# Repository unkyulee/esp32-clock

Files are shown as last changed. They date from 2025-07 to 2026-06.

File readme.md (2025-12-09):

# The Clock 

"The Clock" is a DIY project for people who care about how things look as much as how they work. Clean, minimal, and a little bit obsessive, it is designed to evolve over time. New design ideas, new cases, new features. The long term goal is to build the ultimate desk clock.

---

## What is this project about?

The Clock is:

* A beautiful desk clock that feels at home next to a notebook, a mechanical keyboard, or your favorite pen.
* DIY friendly, using simple materials and straightforward steps.
* Design first, with focus on proportions, light, texture, and shape.
* Iterative, improving in small steps toward a more refined result each time.

---

## What can it do?

Right now, The Clock focuses on doing the basics really well:

* Show the time
* Sync automatically over WiFi
* Optional alarm with a small buzzer

## BOM

- 4x M3 Hex Screw Length 20mm
- 4x M3 Heated Inserts OD 4.5mm Length 3mm
- 1x [EC11 15mm Half handle](https://it.aliexpress.com/item/1005005983134515.html) 
- ESP32 S3 
- [ILI9341 320 \* 240 TFT LCD display](https://www.amazon.it/DIYmalls-Display-ILI9341-Resisive-320x240/dp/B0D8BLFJXG)
- [SPEAKER BUZZER 13 mm](https://www.amazon.it/SPEAKER-13x2-5mm-cicalino-altoparlante-piezoelettrico/dp/B084KLCRGG)
- ESP32 S3

## Wiring

| ESP32 | Connects to  |
| ----- | --- |
| 13 | Display MISO |
| 12 | SCLK |
| 11 | MOSI |
| 10 | CS |
| 46 | DC |
| 3 | RST |
| | |
| 40 | EC11 Switch  |
| 45 | EC11 A |
| 48 | EC11 B |
| | |
| 7 | Buzzer (+) |
| GND | Buzzer (-) |

Bridge the display VCC and LED

## Firmware

* Use Visual Studio with PlatformIO plugin installed
* Open the folder "Rev.2/platformio" 
* Wait for the plugins and library installed
* Open PlatformIO tab, and "Build and Upload" while ESP32 is plugged to PC

## 3D Files

STL files are available from the following link

* [3D Design Files](https://github.com/unkyulee/esp32-clock/tree/main/Rev.2/STL)

## Support

The Clock is an open-source project, built and nurtured with curiosity, care, and a genuine love for DIY enthusiasts. If you've enjoyed exploring the project or building your own Clock, and you'd like to show some support, even a small gesture goes a long way. Every contribution helps me continue improving The Clock Project and sharing it with the community.  

* [Buy me a coffee](https://www.buymeacoffee.com/unkyulee)  

## License

Creative Commons Legal Code

Attribution-NonCommercial 4.0 International

CC BY-NC 4.0

This is a human-readable summary of (and not a substitute for) the license. Disclaimer.

You are free to:

Share — copy and redistribute the material in any medium or format
Adapt — remix, transform, and build upon the material
The licensor cannot revoke these freedoms as long as you follow the license terms.

Under the following terms:

Attribution — You must give appropriate credit, provide a link to the license, and indicate if changes were made. You may do so in any reasonable manner, but not in any way that suggests the licensor endorses you or your use.

NonCommercial — You may not use the material for commercial purposes.

No additional restrictions — You may not apply legal terms or technological measures that legally restrict others from doing anything the license permits.

Notices:

You do not have to comply with the license for elements of the material in the public domain or where your use is permitted by an applicable exception or limitation.
No warranties are given. The license may not give you all of the permissions necessary for your intended use. For example, other rights such as publicity, privacy, or moral rights may limit how you use the material.

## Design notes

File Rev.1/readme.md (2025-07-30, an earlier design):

# WiFi Digital Clock with ESP32

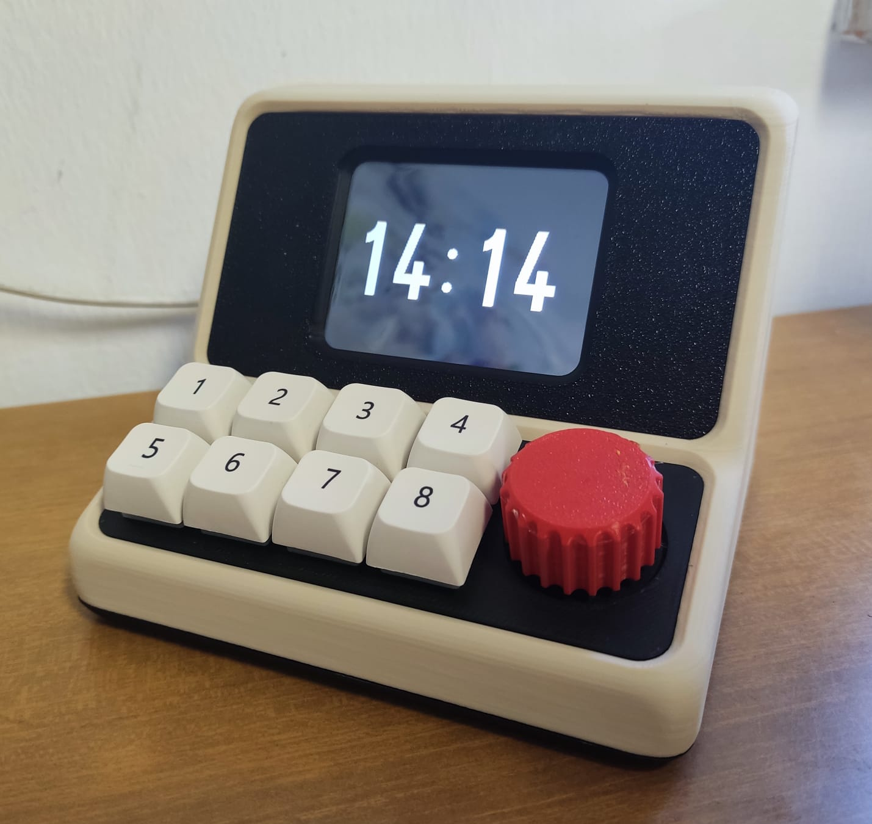
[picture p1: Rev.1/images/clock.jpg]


### BOM

- 4x M3 Hex Screw Length 5mm
- 4x M3 Heated Inserts OD 4.5mm Length 3mm
- 1x [EC11 15mm Half handle](https://it.aliexpress.com/item/1005005983134515.html) 
- ESP32 S3 
- [ILI9341 320 \* 240 TFT LCD display](https://www.amazon.it/DIYmalls-Display-ILI9341-Resisive-320x240/dp/B0D8BLFJXG)
- 8x Cherry MX compatible switches
- [SPEAKER BUZZER 13 mm](https://www.amazon.it/SPEAKER-13x2-5mm-cicalino-altoparlante-piezoelettrico/dp/B084KLCRGG)

### Wiring

| ESP32 | Connects to  |
| ----- | --- |
| 13 | Display MISO |
| 12 | SCLK |
| 11 | MOSI |
| 10 | CS |
| 46 | DC |
| 3 | RST |
| | |
| 15 | Button 1 |
| 16 | Button 2 |
| 17 | Button 3 |
| 18 | Button 4 |
| 1 | Button 5 |
| 2 | Button 6 |
| 42 | Button 7 |
| 41 | Button 8 |
| | |
| 40 | EC11 Switch  |
| 45 | EC11 A |
| 48 | EC11 B |
| | |
| 7 | Buzzer |

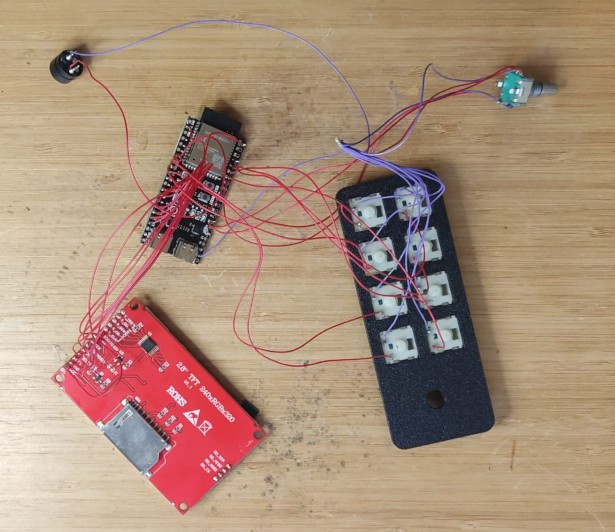
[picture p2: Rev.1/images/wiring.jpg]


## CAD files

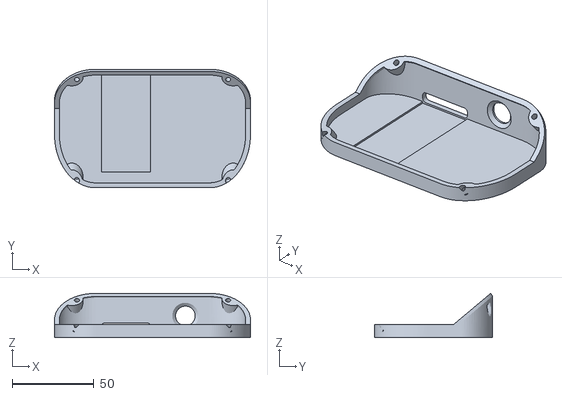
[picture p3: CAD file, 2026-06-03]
Rev.2/STL/Bottom Enclosure.stl
120.0 x 72.5 x 27.0

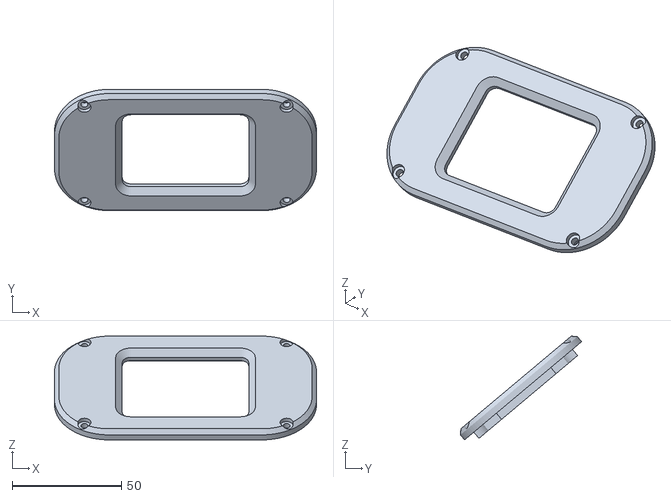
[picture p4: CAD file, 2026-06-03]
Rev.2/STL/Display Plate.stl
120.0 x 55.6 x 47.5

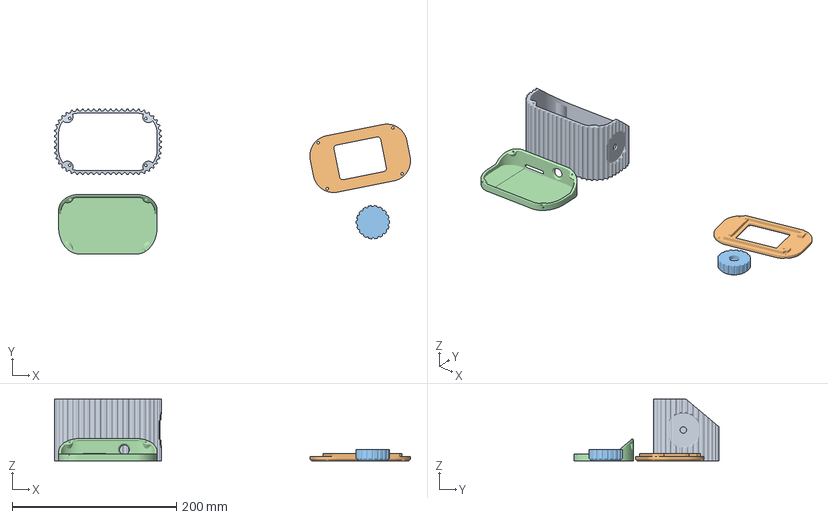
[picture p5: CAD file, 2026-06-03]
Rev.2/STL/clock.3mf
433.5 x 176.5 x 75.0 mm
Enclosure.stl
Display Plate.stl
Knob.stl
Bottom Enclosure.stl

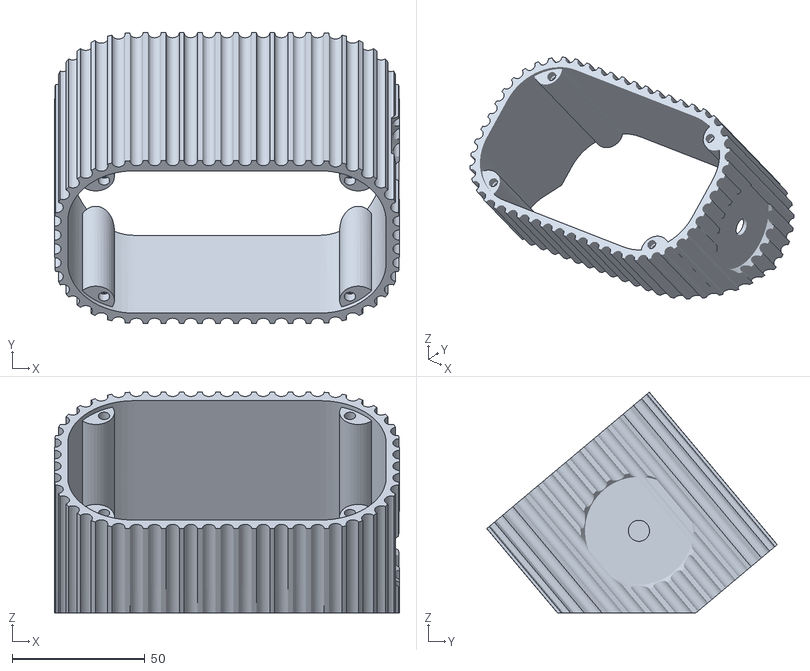
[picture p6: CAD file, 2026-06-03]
Rev.2/STL/Enclosure.stl
130.0 x 109.5 x 83.2

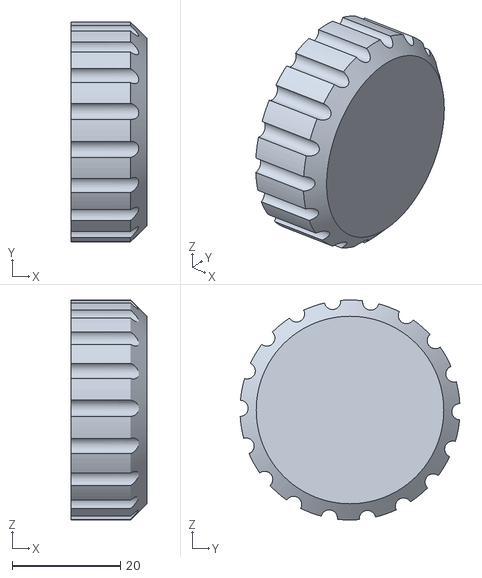
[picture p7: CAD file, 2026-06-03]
Rev.2/STL/Knob.stl
14.0 x 40.6 x 40.6

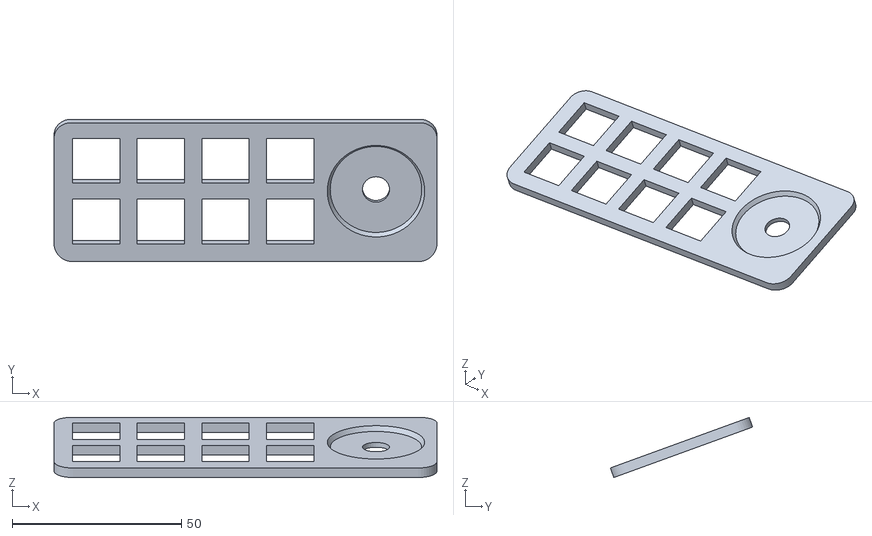
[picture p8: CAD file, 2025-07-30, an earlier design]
Rev.1/STL/Keyboard Plate.stl
113.0 x 42.0 x 17.7

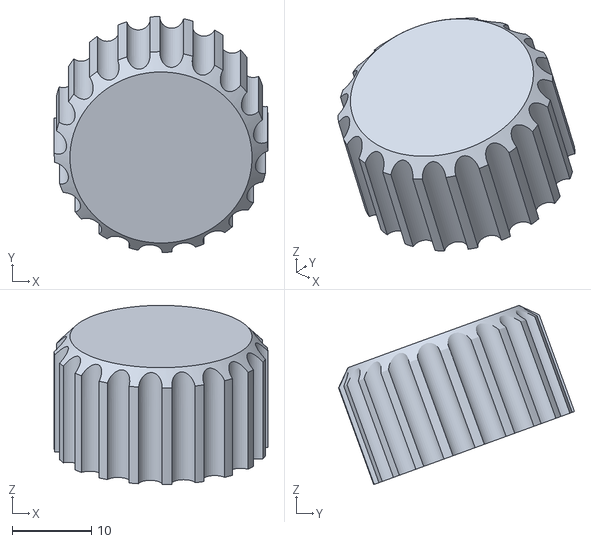
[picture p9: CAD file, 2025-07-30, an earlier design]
Rev.1/STL/Knob.stl
27.0 x 29.8 x 22.6

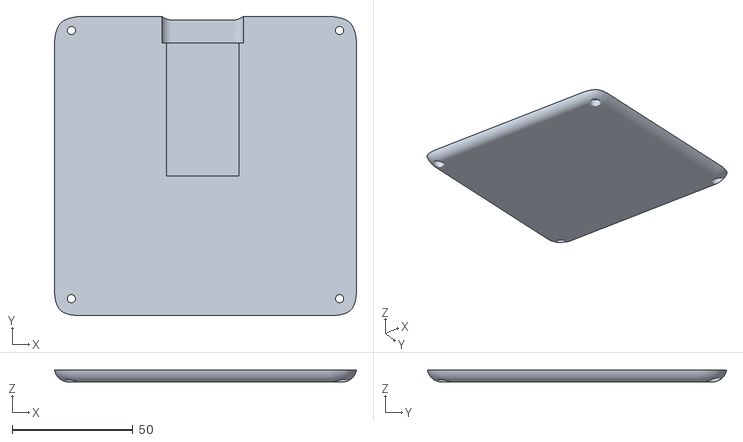
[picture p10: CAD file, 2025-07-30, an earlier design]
Rev.1/STL/Enclosure Bottom.stl
124.8 x 123.7 x 5.00

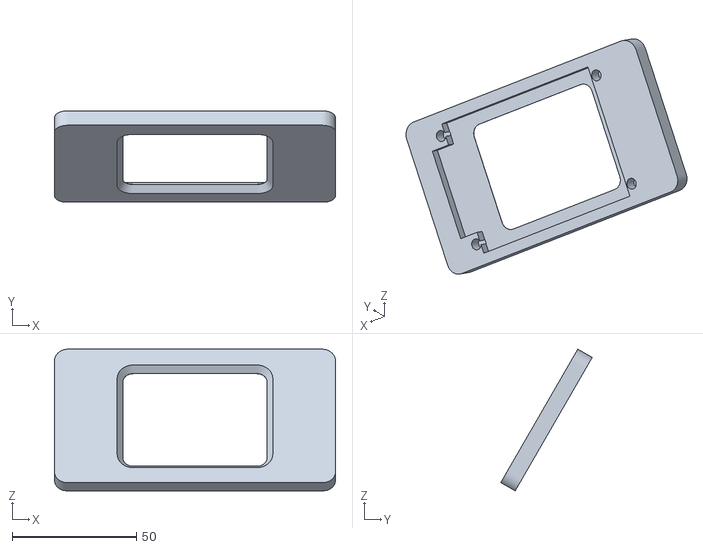
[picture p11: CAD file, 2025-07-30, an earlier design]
Rev.1/STL/Display Plate.stl
113.0 x 36.8 x 57.0

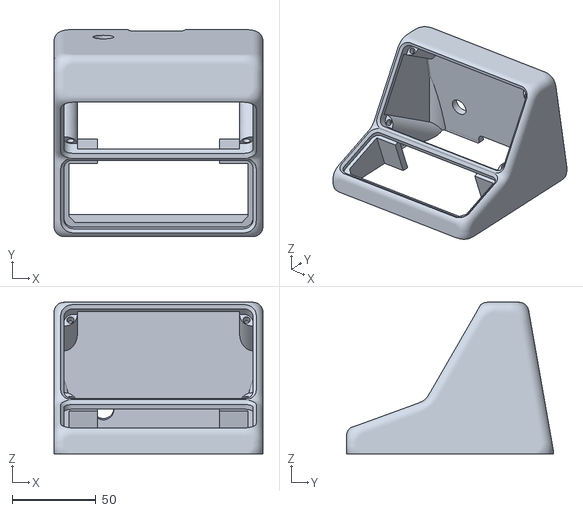
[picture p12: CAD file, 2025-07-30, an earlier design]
Rev.1/STL/Enclosure Top.stl
125.0 x 123.8 x 90.6

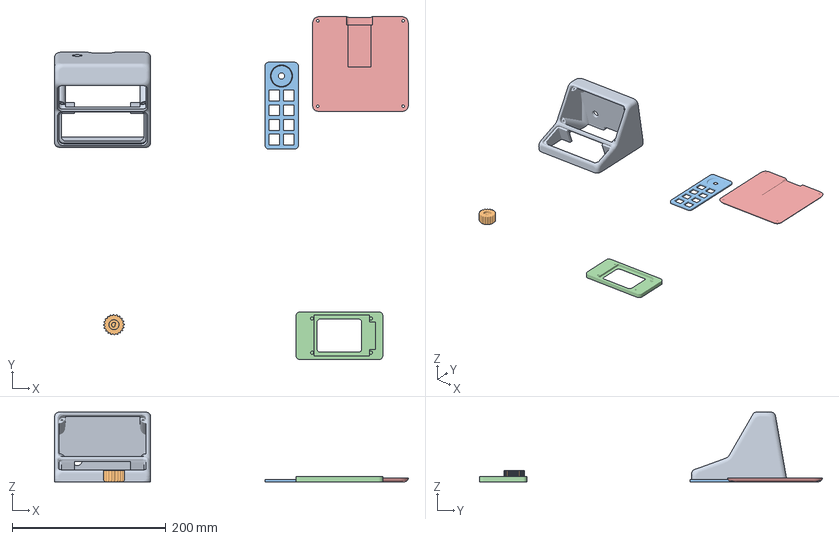
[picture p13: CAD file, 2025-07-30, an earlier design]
Rev.1/STL/esp32-clock.3mf
460.0 x 446.0 x 90.6 mm
Enclosure Top.stl
Knob.stl
Keyboard Plate.stl
Display Plate.stl
Enclosure Bottom.stl

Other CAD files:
Rev.1/STL/ESP32 Clock.f3d

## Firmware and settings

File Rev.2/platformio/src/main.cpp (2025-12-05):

#include <Arduino.h>

// logging and status
#include "app/app.h"

// display
#include "display/display.h"

// input
#include "service/Knob/Knob.h"

//
void TaskCore1(void *pvParameters);

/*----------------------------------------------
Dual Core: First Core
First core will have slightly higher priority
to it will take the critical tasks such as
keyboard input and user interactionss
----------------------------------------------*/
void setup()
{
    // initialize app
    app_setup();

    //
    display_setup();

    // single knob input
    knob_setup();

    // Start the second core task
    xTaskCreatePinnedToCore(
        TaskCore1,   // Function to run
        "TaskCore1", // Name
        8192,        // Stack size
        NULL,        // Parameters
        1,           // Priority
        NULL,        // Task handle
        1            // Core 1
    );
}

//
void loop()
{
    // in ESP32 main core ID is 1
    display_loop();

    // poll knob
    knob_loop();

    // try to yield to avoid infinite loop
    yield();
}

/*----------------------------------------------
Dual Core: Second Core
Second core will contain tasks that can get blocked
and slowed and yet has still less impact.
Such as background tasks.
----------------------------------------------*/
//
void TaskCore1(void *pvParameters)
{
    _log("TaskCore1 Started\n");

    //
    while (1)
    {
        //
        app_loop();

        //
        yield();
    }
}

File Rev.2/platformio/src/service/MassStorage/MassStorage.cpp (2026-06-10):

#include "app/app.h"
#include "MassStorage.h"

USBMSC FatFSUSBClass::msc;
wl_handle_t FatFSUSBClass::wlHandle = WL_INVALID_HANDLE;
uint8_t *FatFSUSBClass::sectorBuffer = nullptr;

bool FatFSUSBClass::usbStarted = false;
bool FatFSUSBClass::usbConfigured = false;
volatile bool FatFSUSBClass::hostConnected = false;
bool FatFSUSBClass::mediaStarted = false;
bool FatFSUSBClass::ejected = false;

uint32_t FatFSUSBClass::blockCount = 0;
uint16_t FatFSUSBClass::blockSize = 0;
size_t FatFSUSBClass::mediaSize = 0;

FatFSUSBClass FatFSUSB;

//
void ms_setup()
{
    JsonDocument &app = status();
    app["usbConnected"] = false;
    app["massStorage"] = false;
    app["massStorageStarted"] = false;
    app["massStorageEjected"] = false;

    if (FatFSUSB.setupUSB())
    {
        _log("USB Mass Storage waiting for host\n");
    }
    else
    {
        _log("USB Mass Storage setup failed\n");
    }
}

//
void ms_loop()
{
    static unsigned int last = millis();

    if (millis() - last <= 1000)
    {
        return;
    }

    last = millis();

    JsonDocument &app = status();

    bool usbConnected = FatFSUSB.isHostConnected();
    bool massStorageEjected = FatFSUSB.isEjected();
    bool massStorageRequest = usbConnected && !massStorageEjected;
    bool massStorageStarted = app["massStorageStarted"].as<bool>();

    app["usbConnected"] = usbConnected;
    app["massStorage"] = massStorageRequest;
    app["massStorageEjected"] = massStorageEjected;

    if (massStorageRequest)
    {
        if (!massStorageStarted)
        {
            // disactivate FAT file system before Mass Storage
            gfs()->end();
            
            if (FatFSUSB.begin())
            {
                app["massStorageStarted"] = true;
                _log("FatFSUSB begin\n");
            }
            else
            {
                app["massStorageStarted"] = false;
                app["massStorage"] = false;
                _log("FatFSUSB begin failed\n");
                return;
            }
        }

        if (FatFSUSB.isConnected() == 0)
        {
            _log("Mass Storage Ejected\n");

            FatFSUSB.end();

            app["massStorageStarted"] = false;
            app["massStorage"] = false;
            app["massStorageEjected"] = true;

            if (gfs()->begin())
            {
                _log("FAT file system restored\n");
            }
            else
            {
                _log("FAT file system restore failed\n");
            }

            _log("FatFSUSB ejected\n");
        }
    }
    else
    {
        if (massStorageStarted)
        {
            FatFSUSB.end();

            app["massStorageStarted"] = false;
            app["massStorageEjected"] = FatFSUSB.isEjected();

            if (gfs()->begin())
            {
                _log("FAT file system restored\n");
            }
            else
            {
                _log("FAT file system restore failed\n");
            }

            _log("FatFSUSB end\n");
        }
    }
}

bool FatFSUSBClass::setupUSB()
{
    if (!usbConfigured)
    {
        USB.onEvent(usbEventCallback);

        msc.vendorID("ESP32S3");
        msc.productID("FlashDisk");
        msc.productRevision("1.0");

        msc.onRead(readCallback);
        msc.onWrite(writeCallback);
        msc.onStartStop(startStopCallback);
        msc.mediaPresent(false);

        usbConfigured = true;
    }

    if (!usbStarted)
    {
        usbStarted = USB.begin();
    }

    return usbStarted;
}

bool FatFSUSBClass::begin()
{
    if (mediaStarted)
    {
        return true;
    }

    if (!setupUSB())
    {
        Serial.println("MassStorageESP32: USB begin failed");
        return false;
    }

    const esp_partition_t *partition = esp_partition_find_first(
        ESP_PARTITION_TYPE_DATA,
        ESP_PARTITION_SUBTYPE_DATA_FAT,
        "storage");

    if (partition == nullptr)
    {
        Serial.println("MassStorageESP32: FAT partition 'storage' not found");
        return false;
    }

    esp_err_t err = wl_mount(partition, &wlHandle);

    if (err != ESP_OK)
    {
        Serial.printf("MassStorageESP32: wl_mount failed: %d\n", err);
        wlHandle = WL_INVALID_HANDLE;
        return false;
    }

    size_t wlSectorSize = wl_sector_size(wlHandle);

    if (wlSectorSize == 0 || wlSectorSize > UINT16_MAX)
    {
        Serial.printf(
            "MassStorageESP32: invalid WL sector size: %u\n",
            static_cast<unsigned>(wlSectorSize));

        wl_unmount(wlHandle);
        wlHandle = WL_INVALID_HANDLE;

        return false;
    }

    blockSize = static_cast<uint16_t>(wlSectorSize);
    mediaSize = wl_size(wlHandle);
    blockCount = mediaSize / blockSize;
    mediaSize = static_cast<size_t>(blockCount) * blockSize;

    if (blockCount == 0)
    {
        Serial.println("MassStorageESP32: invalid block count");

        wl_unmount(wlHandle);
        wlHandle = WL_INVALID_HANDLE;

        return false;
    }

    sectorBuffer = static_cast<uint8_t *>(malloc(blockSize));

    if (sectorBuffer == nullptr)
    {
        Serial.printf(
            "MassStorageESP32: sector buffer allocation failed: %u\n",
            blockSize);

        wl_unmount(wlHandle);
        wlHandle = WL_INVALID_HANDLE;
        blockCount = 0;
        blockSize = 0;
        mediaSize = 0;

        return false;
    }

    if (!msc.begin(blockCount, blockSize))
    {
        Serial.println("MassStorageESP32: MSC begin failed");

        free(sectorBuffer);
        sectorBuffer = nullptr;

        wl_unmount(wlHandle);
        wlHandle = WL_INVALID_HANDLE;
        blockCount = 0;
        blockSize = 0;
        mediaSize = 0;

        return false;
    }

    msc.mediaPresent(true);

    mediaStarted = true;
    ejected = false;

    Serial.printf(
        "MassStorageESP32: started, blocks=%lu, blockSize=%u\n",
        static_cast<unsigned long>(blockCount),
        blockSize);

    return true;
}

void FatFSUSBClass::end()
{
    if (!mediaStarted)
    {
        return;
    }

    msc.mediaPresent(false);

    if (wlHandle != WL_INVALID_HANDLE)
    {
        wl_unmount(wlHandle);
        wlHandle = WL_INVALID_HANDLE;
    }

    free(sectorBuffer);
    sectorBuffer = nullptr;

    mediaStarted = false;
    blockCount = 0;
    blockSize = 0;
    mediaSize = 0;

    Serial.println("MassStorageESP32: ended");
}

void FatFSUSBClass::unplug()
{
    if (!mediaStarted)
    {
        return;
    }

    msc.mediaPresent(false);
    ejected = true;

    Serial.println("MassStorageESP32: media unplugged");
}

bool FatFSUSBClass::isConnected()
{
    return mediaStarted && hostConnected && !ejected;
}

bool FatFSUSBClass::isHostConnected()
{
    return hostConnected;
}

bool FatFSUSBClass::isEjected()
{
    return ejected;
}
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

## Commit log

2025-07-30 Reset commit history
    [Display Plate.stl, ESP32 Clock.f3d, Enclosure Bottom.stl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]
2025-12-05 draft rev.2. The Clock
    [Bottom Enclosure.stl, Display Plate.stl, ESP32 Clock.f3d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]
2025-12-07 The Clock Project
    [Display Plate.stl]
2025-12-13 alarm edge case fixed
2026-06-03 reset when wifi doesn't get connected
    [Bottom Enclosure.stl, Display Plate.stl, Enclosure.stl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]
2026-06-10 changes in the filesystem to FAT
    [partition_esp32s3_rev8_16mb.csv]
